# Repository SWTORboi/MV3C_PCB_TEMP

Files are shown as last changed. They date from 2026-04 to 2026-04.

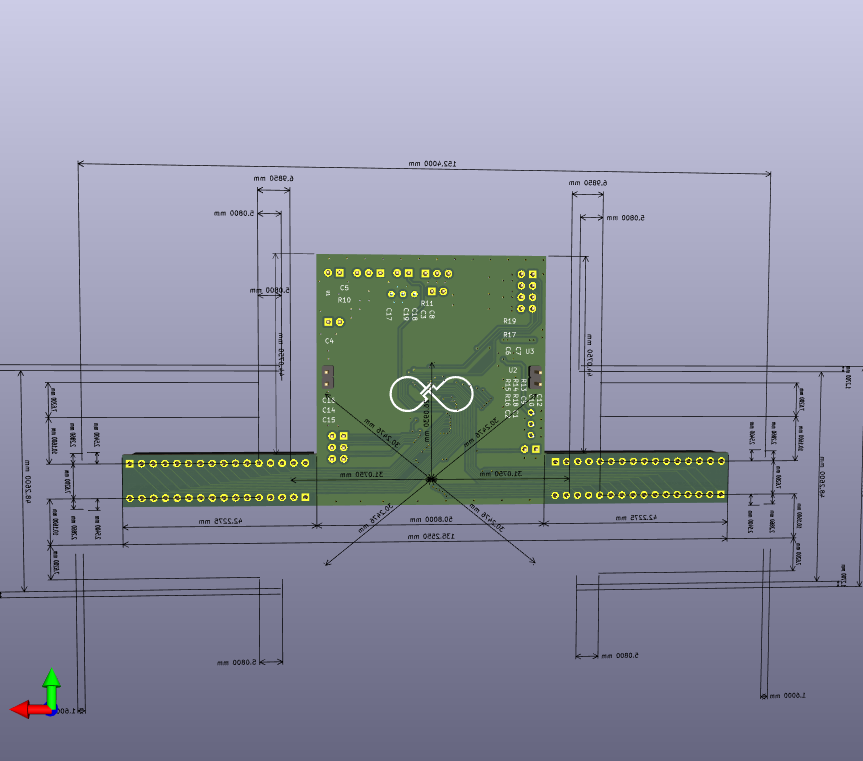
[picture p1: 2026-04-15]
V3_Motherboard/docs/MOSbiusPCB_v4a_2026_Back.png

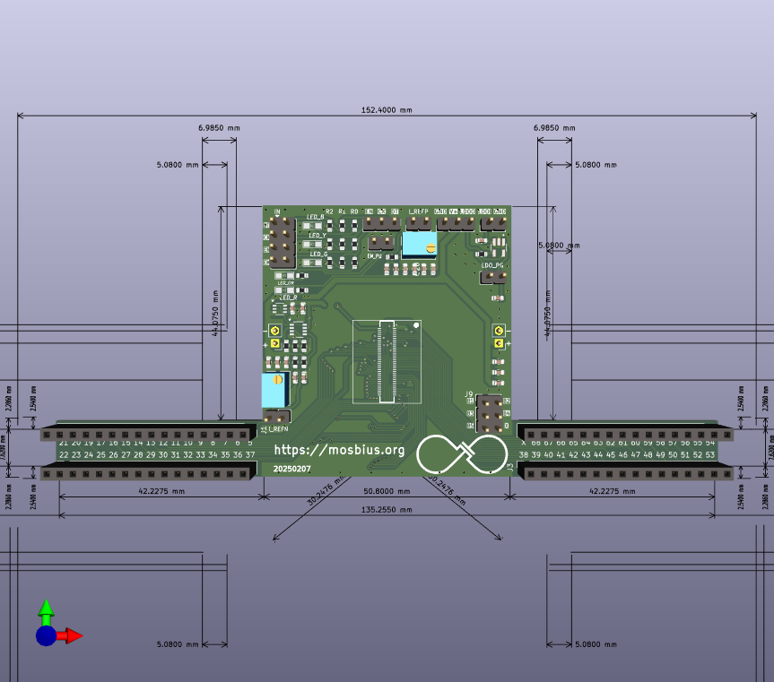
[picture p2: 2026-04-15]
V3_Motherboard/docs/MOSbiusPCB_v4a_2026_Front.png

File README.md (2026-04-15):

# MV3C_PCB_TEMP
Temporary View Repo for V3 COB Breakout PCB (v4a_2026)

Changes from V1 Chip PCB (v3b_2025)

1. Pin bindings changed according to pin bindings .csv and WaferSpace_COB_70pins/V3_COB_Original, COB mounting footprint replaced chip socket
    a. Added Bus 1-5 pins, routed out through 2x3 header pin Breakout
    b. Removed NPAIR_4_BODY, PPAIR_4_BODY, ISINK_32 pins
    c. Changed trace width from standard .25 to .15

Further design considerations and questions

1. LDO - Already have voltage supply protection, is there any reason of convenience to keep LDO for 2.5V or other voltage
2. Power Net Switch - Is it desireable to have an aditional low drop mechanical switch for power net for chip safety
3. Feedback from V1 board - Are there any issues with original V1 design that need to be addressed

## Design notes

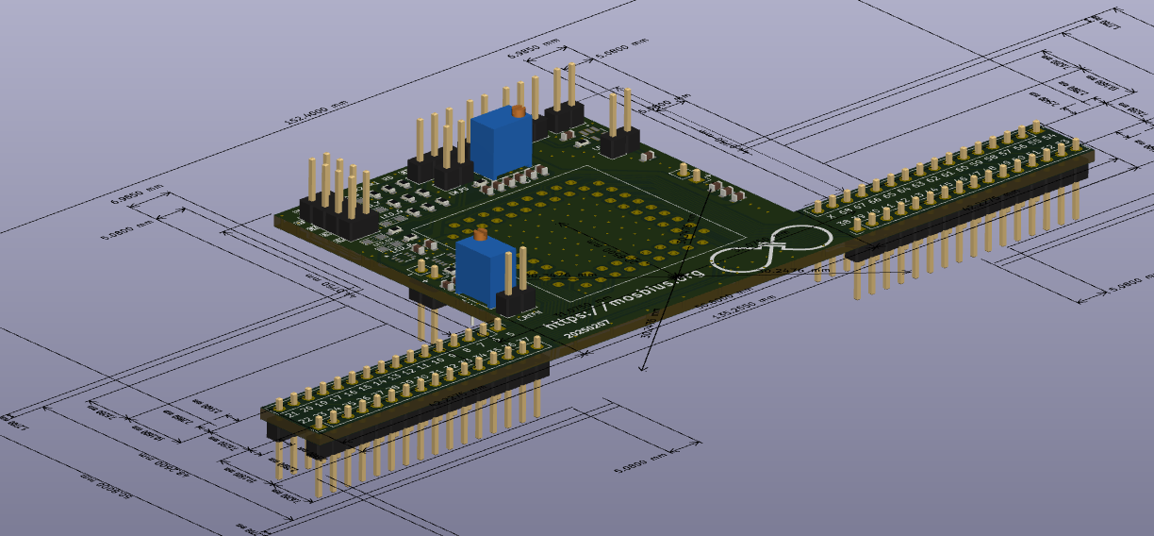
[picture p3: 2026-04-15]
V3_Motherboard/3D/Screenshot 2025-02-14 at 1.38.24 PM.png

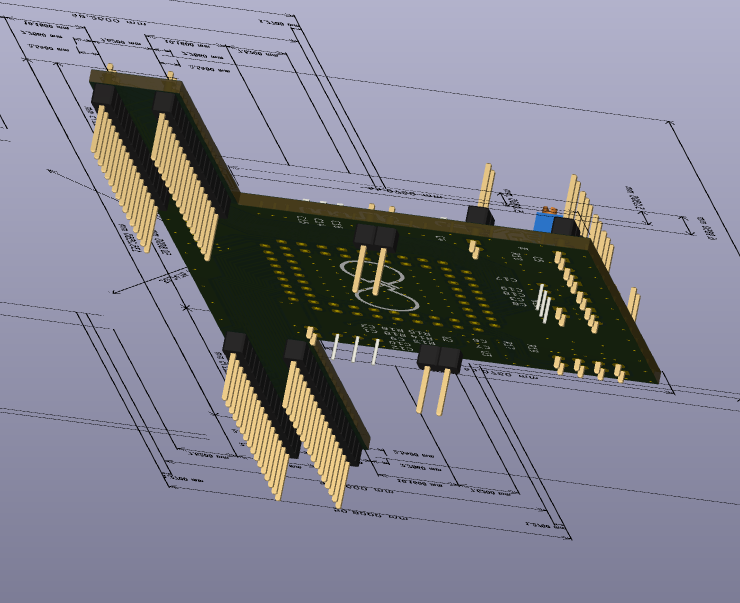
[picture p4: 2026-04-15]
V3_Motherboard/3D/Screenshot 2025-02-14 at 1.38.48 PM.png

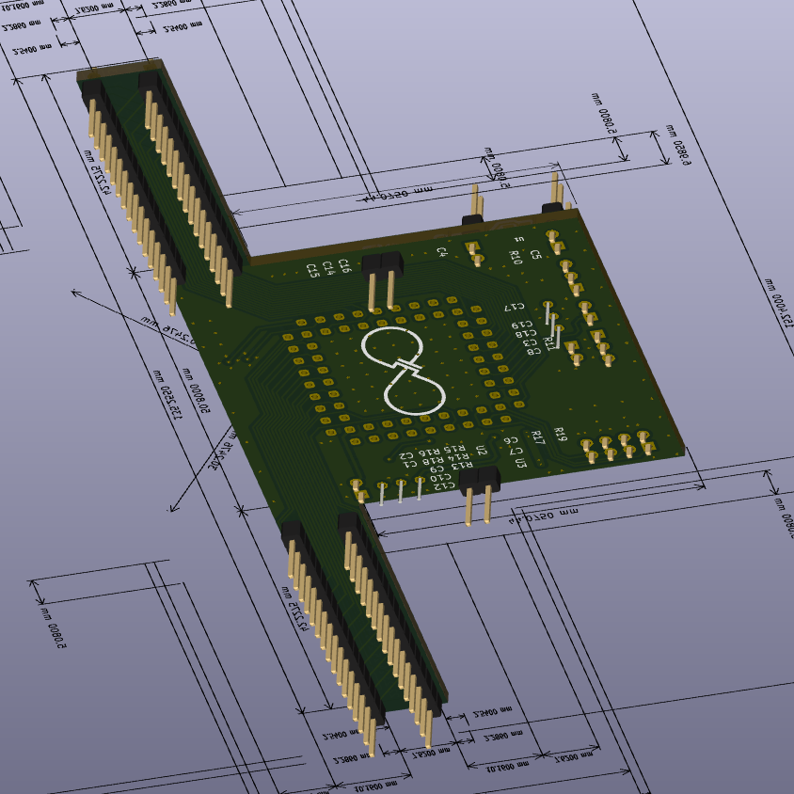
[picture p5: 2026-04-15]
V3_Motherboard/3D/Screenshot 2025-02-14 at 1.39.02 PM.png

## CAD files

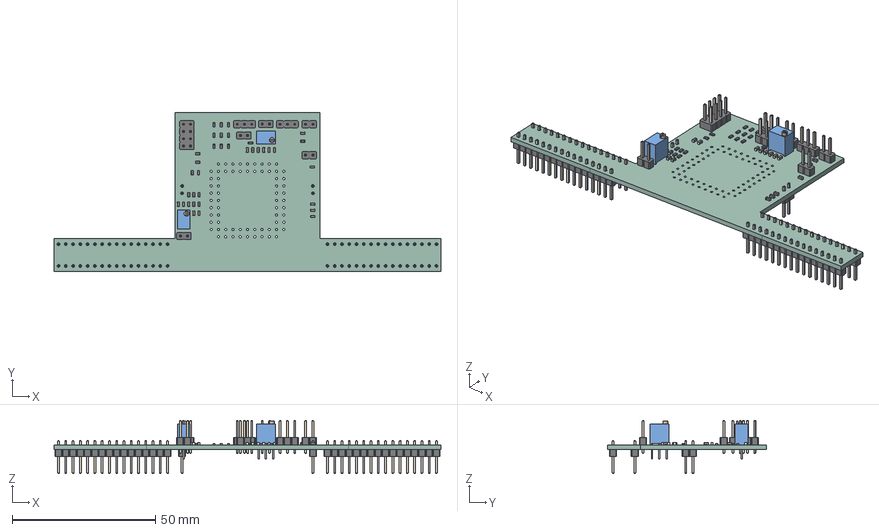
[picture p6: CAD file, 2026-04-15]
V3_Motherboard/V3_Motherboard.step
135.3 x 55.5 x 18.6 mm
C_0603_1608Metric x 18
PinHeader_1x02_P254mm_Vertical x 7
R_0603_1608Metric x 18
Potentiometer_Bourns_3266Y_Vertical x 2
PinHeader_1x16_P254mm_Vertical x 4
PinHeader_1x03_P254mm_Vertical x 2
PinHeader_2x04_P254mm_Vertical
MOSbiusPCB_v3b_2024_PCB

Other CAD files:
V3_Motherboard/V3_Motherboard.stl

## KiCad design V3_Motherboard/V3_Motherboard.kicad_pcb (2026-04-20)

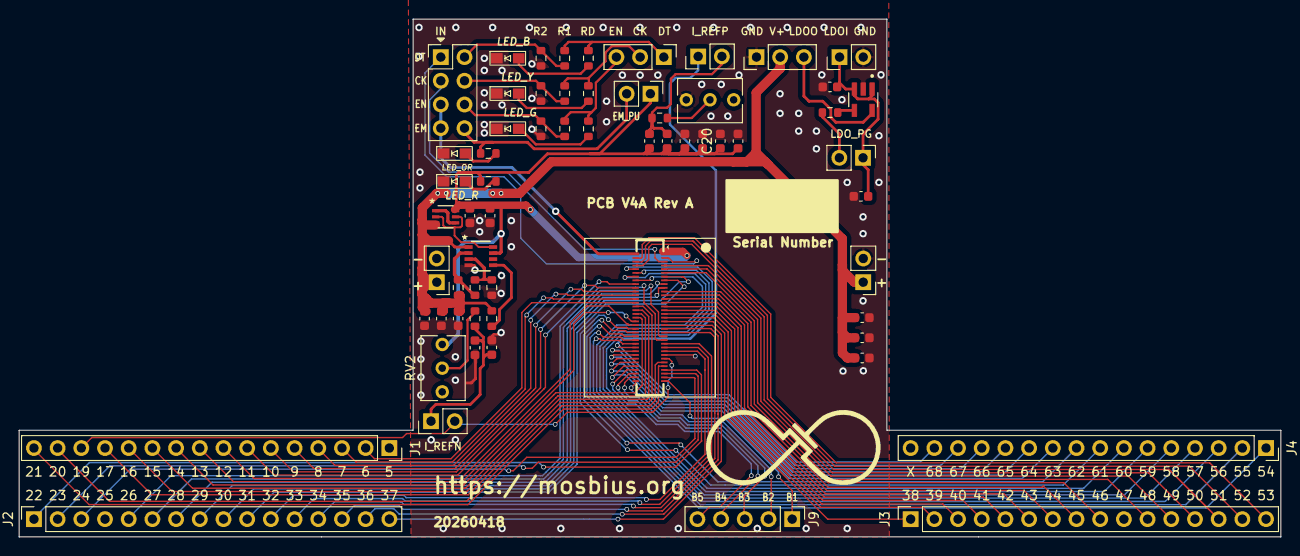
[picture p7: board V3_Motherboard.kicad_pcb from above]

Board: 2 copper layers, 135.3 x 55.5 mm, 62 parts (0 on the bottom side), 96 nets.

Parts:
C1, C4, C6, C8, C9, C15, C18: 1u; C_0603_1608Metric
C2, C3, C7, C10, C16, C17: 0.1u; C_0603_1608Metric
C5, C12, C14, C19: 10u; C_0603_1608Metric
C20: 47u; C_0603_1608Metric
D1: LED_OR; SunLED_LED_XZC_0805
D2: LED_G; SunLED_LED_XZC_0805
D3: LED_Y; SunLED_LED_XZC_0805
D4: LED_B; SunLED_LED_XZC_0805
D5: LED_R; SunLED_LED_XZC_0805
J1, J2, J3, J4: Conn_01x16_Pin; PinSocket_1x16_P2.54mm_Vertical
J5, J7, J8: PINHD_1x2_Male; PinHeader_1x02_P2.54mm_Vertical
J6: Conn_01x02_Pin; PinHeader_1x02_P2.54mm_Vertical
J9: Conn_01x05_Pin; PinHeader_1x05_P2.54mm_Vertical
J10: Conn_02x04_Row_Letter_First; PinHeader_2x04_P2.54mm_Vertical
J14_GND2, J14_GND3: Conn_01x03; PinHeader_1x03_P2.54mm_Vertical
J18_VDC1: Conn_01x02; PinHeader_1x02_P2.54mm_Vertical
JP1_LDOPG1, JP2_EN1: Jumper_2_Open; PinHeader_1x02_P2.54mm_Vertical
R1, R3, R5, R11, R18: 1.1k; R_0603_1608Metric
R2, R4, R6: 3.3k; R_0603_1608Metric
R7, R9, R17, R19: 330; R_0603_1608Metric
R8: 750; R_0603_1608Metric
R10: 10K; R_0603_1608Metric
R13, R16: 0; R_0603_1608Metric
R14: 510K; R_0603_1608Metric
R15: 120K; R_0603_1608Metric
RV1, RV2: 25k_POT; Potentiometer_Bourns_3266Y_Vertical
U1: NCV8164ASN250T1G_LDO_2.5V; NCV8164ASN250T1G
U2: LTC4365TS8; TSOT-23_TS8_LIT
U3: UM6K34NTCN; TRANS_UM6J1_ROM
U4: P0.40_HC-PBB40C-70DS-0.4V-3.0-02_wscob

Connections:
/BUS1: J9.1, U4.35 (pad_46)
/BUS2: J9.2, U4.36 (pad_44)
/BUS3: J9.3, U4.37 (pad_43)
/BUS4: J9.4, U4.38 (pad_42)
/BUS5: J9.5, U4.39 (pad_41)
/CMFB_OTA2_INN: J4.2, U4.47 (pad_32)
/CMFB_OTA2_INP: J4.3, U4.46 (VDD_CORE)
/CMFB_OTA2_OUT: J4.1, U4.48 (pad_31)
/INV_TPLGY16_1INN: J3.16, U4.69 (pad_10)
/INV_TPLGY16_1INP: J3.15, U4.68 (pad_11)
/INV_TPLGY16_1OUT: J3.14, U4.67 (pad_12)
/INV_TPLGY16_2INN: J3.11, U4.6 (pad_2)
/INV_TPLGY16_2INP: J3.13, U4.4 (pad_4)
/INV_TPLGY16_2OUT: J3.12, U4.5 (pad_3)
/ISINIK_REF2: J2.5, U4.24 (VDD_IO)
/ISINK_1: J1.15, U4.30 (pad_51)
/ISINK_2: J1.16, U4.31 (pad_50)
/ISINK_4: J2.1, U4.32 (pad_49)
/ISINK_8: J2.2, U4.33 (pad_48)
/ISINK_16: J2.3, U4.34 (pad_47)
/ISINK_REF2_CPY: J2.6, U4.23 (pad_58)
/I_SOURCE_1: J4.14, U4.44 (VDD_IO)
/I_SOURCE_2: J4.13, U4.43 (pad_37)
/I_SOURCE_4: J4.12, U4.42 (pad_38)
/I_SOURCE_8: J4.11, U4.41 (pad_39)
/I_SOURCE_16: J4.10, U4.40 (pad_40)
/I_SOURCE_REF2: J4.9, U4.49 (pad_30)
/I_SOURCE_REF2_CPY: J4.8, U4.50 (pad_29)
/NMOS_4A_DRAIN: J2.8, U4.10 (GND)
/NMOS_4A_GATE: J2.7, U4.9 (VDD_IO)
/NMOS_4B_DRAIN: J2.10, U4.8 (pad_0)
/NMOS_4B_GATE: J2.9, U4.7 (pad_1)
/NPAIR_4A_DRAIN: J3.4, U4.16 (pad_65)
/NPAIR_4A_GATE: J3.5, U4.15 (pad_66)
/NPAIR_4A_SOURCE: J3.6, U4.14 (pad_67)
/NPAIR_4B_DRAIN: J3.9, U4.11 (VDD_CORE)
/NPAIR_4B_GATE: J3.8, U4.12 (pad_69)
/NPAIR_4B_SOURCE: J3.7, U4.13 (pad_68)
/NPAIR_A_DRAIN: J2.14, U4.22 (pad_59)
/NPAIR_A_GATE: J2.15, U4.21 (pad_60)
/NPAIR_A_SOURCE: J2.16, U4.20 (pad_61)
/NPAIR_B_DRAIN: J3.3, U4.17 (pad_64)
/NPAIR_B_GATE: J3.2, U4.18 (GND)
/NPAIR_B_SOURCE: J3.1, U4.19 (PWR_AUX)
/OTA_N_INN: J2.12, U4.26 (pad_55)
/OTA_N_INP: J2.11, U4.27 (pad_54)
/OTA_N_OUT: J2.13, U4.25 (GND)
/PMOS_4A_DRAIN: J4.6, U4.65 (pad_14)
/PMOS_4A_GATE: J4.7, U4.66 (pad_13)
/PMOS_4B_DRAIN: J4.4, U4.63 (pad_16)
/PMOS_4B_GATE: J4.5, U4.64 (pad_15)
/PPAIR_4A_DRAIN: J1.7, U4.62 (VDD_IO)
/PPAIR_4A_GATE: J1.6, U4.61 (GND)
/PPAIR_4A_SOURCE: J1.5, U4.60 (pad_19)
/PPAIR_4B_DRAIN: J1.2, U4.57 (pad_22)
/PPAIR_4B_GATE: J1.3, U4.58 (pad_21)
/PPAIR_4B_SOURCE: J1.4, U4.59 (pad_20)
/PPAIR_A_DRAIN: J1.13, U4.56 (pad_23)
/PPAIR_A_GATE: J1.12, U4.55 (pad_24)
/PPAIR_A_SOURCE: J1.11, U4.54 (PWR_AUX)
/PPAIR_B_DRAIN: J1.8, U4.51 (pad_28)
/PPAIR_B_GATE: J1.9, U4.52 (pad_27)
/PPAIR_B_SOURCE: J1.10, U4.53 (GND)
CLK: J10.3, U4.3 (pad_5)
CLK_CVRT_2.5V: J10.4, R3.2, R4.1
CLK_CVRT_3.3V: J14_GND2.2, R3.1, R8.1
DATA: J10.1, U4.2 (pad_6)
DATA_CVRT_2.5V: J10.2, R5.2, R6.1
DATA_CVRT_3.3V: J14_GND2.1, R5.1, R9.1
ENABLE: J10.5, J10.7, U4.70 (pad_9)
EN_CVRT_2.5V: J10.6, R1.2, R2.1
EN_CVRT_3.3V: J14_GND2.3, R1.1, R7.1
EN_MAN_2.5V: J10.8, JP2_EN1.2 (B), R19.1
GND: C1.2, C2.2, C4.2, C5.2, C6.2, C7.2, C9.2, C10.2, C12.2, C14.2, C15.2, C16.2, C17.2, C18.2, C19.2, C20.2, D1.1 (K), D2.1 (K), D3.1 (K), D4.1 (K), D5.1 (K), J5.2, J6.2, J14_GND3.1, J18_VDC1.2, R2.2, R4.2, R6.2, R15.2, RV1.3, U1.2 (GND), U2.4 (GND), U4.28 (pad_53)
ISINK_REF: J1.14, J7.2, U4.29 (pad_52)
I_SOURCE_REF: J4.15, J8.1, U4.45 (GND)
LDO_OUT_2.5V: J14_GND3.3, U1.5 (out)
LDO_PG_2.5V: R10.1, U1.4 (PG)
LDO_VIN: C4.1, C5.1, J18_VDC1.1, JP1_LDOPG1.1 (A), U1.1 (IN), U1.3 (EN)
unnamed: C1.1, C2.1, J7.1, R18.2
unnamed: C3.2, C8.2, J8.2, R11.2
unnamed: D1.2 (A), R19.2
unnamed: D2.2 (A), R7.2
unnamed: D3.2 (A), R8.2
unnamed: D4.2 (A), R9.2
unnamed: D5.2 (A), R17.2
unnamed: JP1_LDOPG1.2 (B), R10.2
unnamed: R11.1, RV1.2
unnamed: R18.1, RV2.2
unnamed: U2.8 (GATE), U3.2, U3.5
unnamed: R14.2, R15.1, U2.3 (OV)
unnamed: R13.2, R14.1, U2.2 (UV)
unnamed: R16.2, U2.5 (~SHDN)
unnamed: U3.1, U3.4
VD: C9.1, C10.1, C12.1, C14.1, C15.1, C16.1, J5.1, J6.1, J14_GND3.2, R13.1, R16.1, U2.1 (Vin), U3.3
VDD: C3.1, C6.1, C7.1, C8.1, C17.1, C18.1, C19.1, C20.1, JP2_EN1.1 (A), R17.1, RV2.1, U2.7 (Vout), U3.6, U4.1 (pad_7)

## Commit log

2026-04-15 Temporary viewing repo for v4a PCB for V3 COB
    [MOSbiusPCB_v4a_2026.kicad_pcb, MOSbiusPCB_v4a_2026.kicad_sch, MOSbiusPCB_v4a_2026.step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]
2026-04-15 Updated Readme and Docs
    [MOSbiusPCB_v4a_2026.kicad_pcb]
2026-04-20 Added pin bindings csv
    [PCB_Pin_Bindings_Extended - Sheet1.csv]
